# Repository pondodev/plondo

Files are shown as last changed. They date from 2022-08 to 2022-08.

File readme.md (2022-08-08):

# plondo

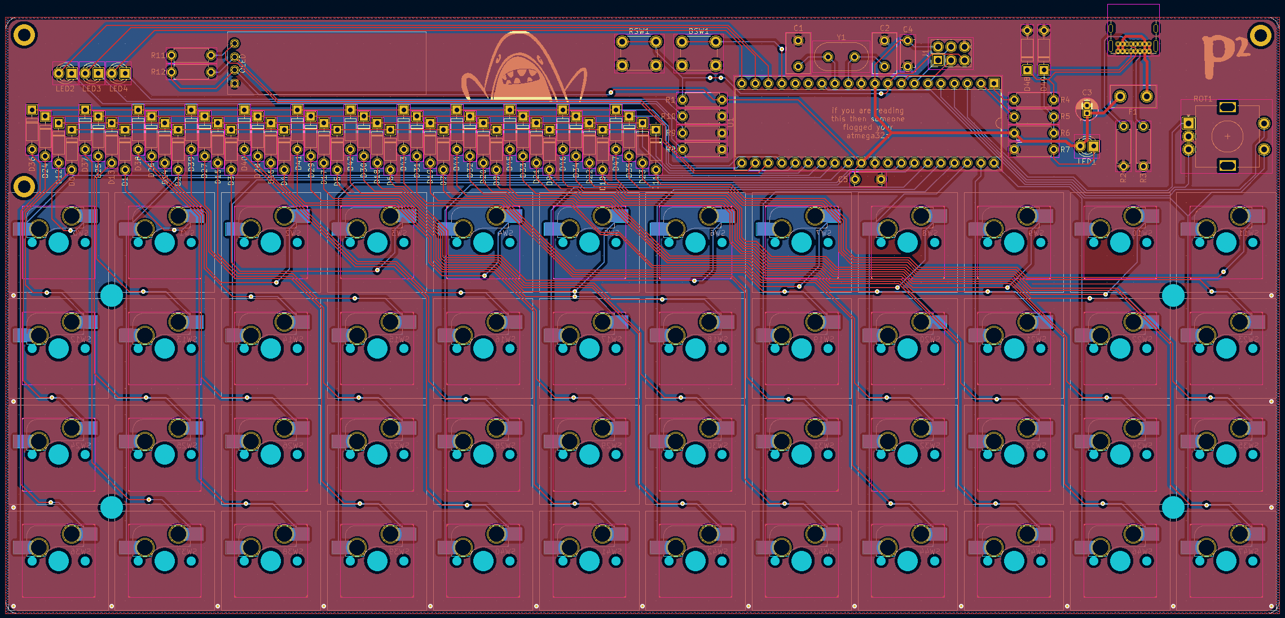
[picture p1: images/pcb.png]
plondo pcb


a plaid inspired 4x12 ortholinear keyboard with a rotary encoder and oled panel.

building plondo? then start at the [BOM](docs/1-bom.md)!

this is a work in progress by me, someone who is a software engineer and very much not qualified to do this kind of
thing. i'm going to do it anyway.

if you're missing symbols/footprints then make sure you run `git submodule init && git submodule update` to pull the
relevant libraries down.

this keyboard derives from the [plaid](https://github.com/hsgw/plaid) and the
[mysterium](https://github.com/coseyfannitutti/mysterium).

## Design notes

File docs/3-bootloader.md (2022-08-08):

# bootloader

to flash the bootloader onto your atmega32a, you need to have some sort of in system programmer (ISP) such as a usbasp
programmer or an arduino. if you don't have one, they're pretty cheap online.
[this is the one that i use](https://core-electronics.com.au/usbasp-usbisp-3-3v-5v-avr-programmer.html), but any ISP
capable of programming AVR chips will do.

next, clone [my fork of usbasploader](https://github.com/pondodev/USBaspLoader) locally and make sure to change the
`PROGRAMMER` variable in `Makefile.inc` to be the programmer that you're using. then simply connect your ISP to your
computer and to the ISP header (J1) on the PCB and run `make fuse && make flash`.

once you're done here, move onto [flashing and testing your PCB](4-flashing.md)

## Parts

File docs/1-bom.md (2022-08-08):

# bill of materials

before you get started, make sure you have the following parts to build your plondo. all parts are through hole unless
otherwise specified.

- 1x plondo PCB set
    - this includes the switch plate, base plate, and main pcb
- 1x atmega32a-p
- 1x 40 pin IC socket
- 48x 1N4148 diodes
- 2x 3.6V zener diodes
- 2x 100nF capacitors
- 1x 4.7uF capacitor
- 2x 20pF capacitors
- 1x USB-4085
- 1x 500mA 5mm pitch fuse
- 1x 16MHz crystal
- 2x push buttons
- 4x LEDs (1 power, 3 indicator)
- 3x 10k ohm resistors
- 4x 1.5k ohm resistors
- 2x 5.1k ohm resistors
- 2x 75 ohm resistors
- 1x ec11 rotary encoder
    - probably also get a knob to go on it
- 48x kailh mx hotswap terminals
- 48x mx compatible switches
- 1x ssd1306 128x32 oled screen
- 1x 2x3 2.54mm pin header
- 14x m2 screws
- 9x m2 spacers (TODO: figure out the sizes we need. 4 for the middle of the board, 5 for the top)
- 1x acrylic cover (optional)

you should probably also have the following tools

- soldering iron
- solder sucker and wick
    - just to clean up joints and desolder if you make mistakes. skip this if you're a giga-chad
- tweezers
- flux
    - this is for the usb c port. good luck without it
- ISP
    - i use a usbasp programmer, these things are super cheap online just make sure you have one for the bootloader
- small screwdriver
- multimeter
    - optional, but helpful for testing your soldering if you think it's dodgy

now that you have all the pieces you need, time to [start building](2-build-guide.md)

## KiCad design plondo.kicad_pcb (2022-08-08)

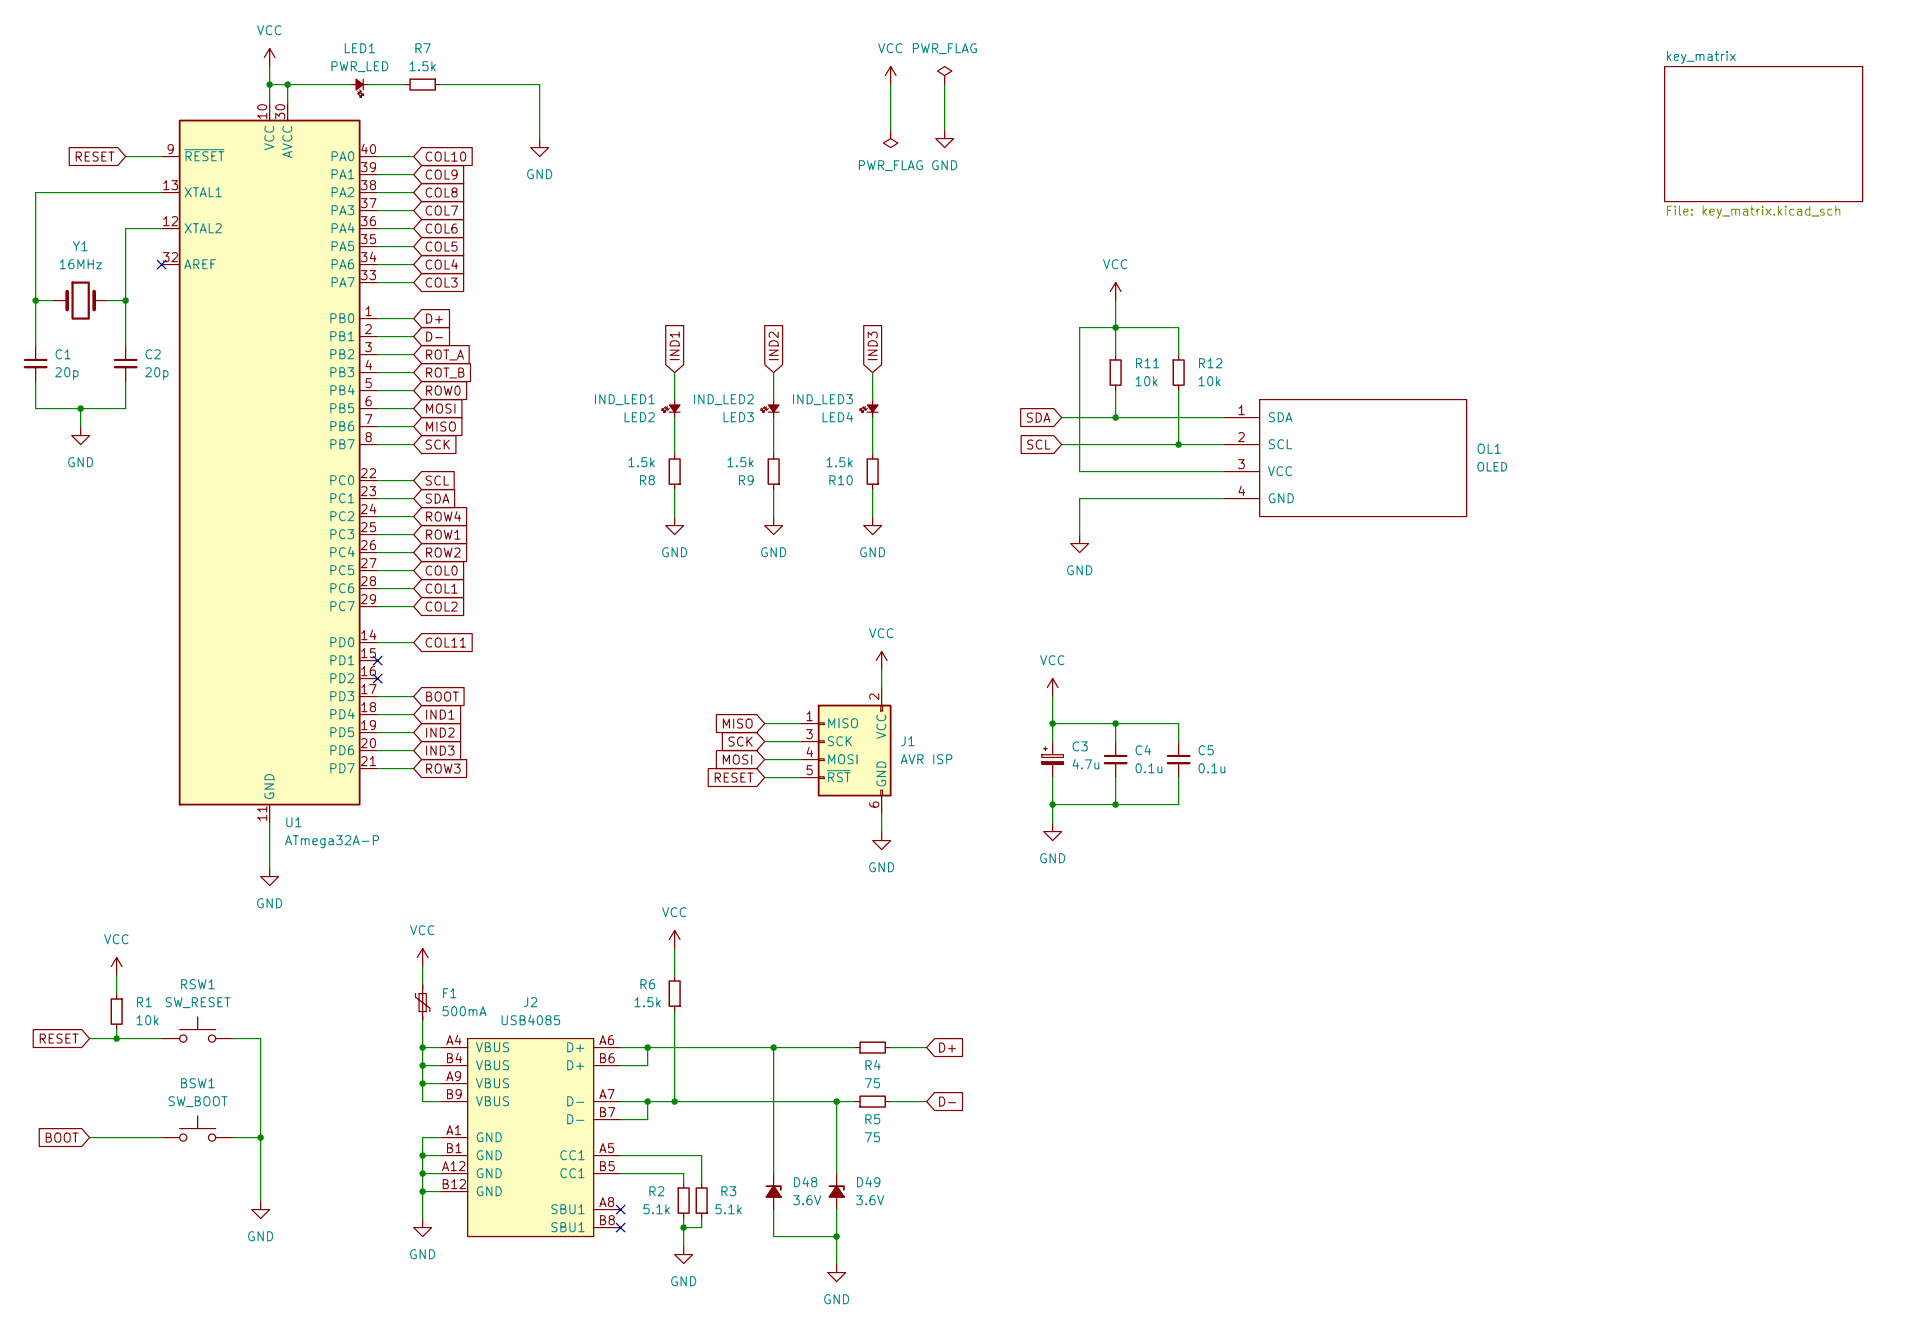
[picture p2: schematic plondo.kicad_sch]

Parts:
BSW1: SW_BOOT; SW_PUSH_6mm_H4.3mm
C1, C2: 20p; C_Disc_D7.5mm_W4.4mm_P5.00mm
C3: 4.7u; CP_Radial_D4.0mm_P1.50mm
C4, C5: 0.1u; C_Disc_D5.0mm_W2.5mm_P5.00mm
D48, D49: 3.6V; D_DO-35_SOD27_P7.62mm_Horizontal
F1: 500mA; Fuse_Littelfuse_395Series
J1: AVR ISP; PinHeader_2x03_P2.54mm_Vertical
J2: USB4085; Farnell 2924867
LED1: PWR_LED; LED_D3.0mm
LED2: IND_LED1; LED_D3.0mm
LED3: IND_LED2; LED_D3.0mm
LED4: IND_LED3; LED_D3.0mm
OL1: OLED; OLED_v2
R1, R11, R12: 10k; R_Axial_DIN0207_L6.3mm_D2.5mm_P7.62mm_Horizontal
R2, R3: 5.1k; R_Axial_DIN0207_L6.3mm_D2.5mm_P7.62mm_Horizontal
R4, R5: 75; R_Axial_DIN0207_L6.3mm_D2.5mm_P7.62mm_Horizontal
R6, R7, R8, R9, R10: 1.5k; R_Axial_DIN0207_L6.3mm_D2.5mm_P7.62mm_Horizontal
RSW1: SW_RESET; SW_PUSH_6mm_H4.3mm
U1: ATmega32A-P; DIP-40_W15.24mm_Socket
Y1: 16MHz; Resonator-2Pin_W10.0mm_H5.0mm

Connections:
BOOT: BSW1.1, U1.17 (PD3)
COL0: U1.27 (PC5); also elsewhere on the board
COL1: U1.28 (PC6); also elsewhere on the board
COL2: U1.29 (PC7); also elsewhere on the board
COL3: U1.33 (PA7); also elsewhere on the board
COL4: U1.34 (PA6); also elsewhere on the board
COL5: U1.35 (PA5); also elsewhere on the board
COL6: U1.36 (PA4); also elsewhere on the board
COL7: U1.37 (PA3); also elsewhere on the board
COL8: U1.38 (PA2); also elsewhere on the board
COL9: U1.39 (PA1); also elsewhere on the board
COL10: U1.40 (PA0); also elsewhere on the board
COL11: U1.14 (PD0); also elsewhere on the board
D+: R4.2, U1.1 (PB0)
D-: R5.2, U1.2 (PB1)
GND: BSW1.2, C1.2, C2.2, C3.2, C4.2, C5.2, D48.2 (A), D49.2 (A), J1.6 (GND), J2.A1 (GND), J2.A12 (GND), J2.B1 (GND), J2.B12 (GND), OL1.4 (GND), R2.2, R3.1, R7.1, R8.1, R9.1, R10.1, RSW1.2, U1.11 (GND), U1.31 (GND); also elsewhere on the board
IND1: LED2.2, U1.18 (PD4)
IND2: LED3.2, U1.19 (PD5)
IND3: LED4.2, U1.20 (PD6)
MISO: J1.1 (MISO), U1.7 (PB6)
MOSI: J1.4 (MOSI), U1.6 (PB5)
unnamed: C1.1, U1.13 (XTAL1), Y1.1
unnamed: C2.1, U1.12 (XTAL2), Y1.2
unnamed: D48.1 (K), J2.A6 (D+), J2.B6 (D+), R4.1
unnamed: D49.1 (K), J2.A7 (D-), J2.B7 (D-), R5.1, R6.1
unnamed: F1.1, J2.A4 (VBUS), J2.A9 (VBUS), J2.B4 (VBUS), J2.B9 (VBUS)
unnamed: J2.A5 (CC1), R3.2
unnamed: J2.B5 (CC1), R2.1
unnamed: LED1.1, R7.2
unnamed: LED2.1, R8.2
unnamed: LED3.1, R9.2
unnamed: LED4.1, R10.2
RESET: J1.5 (~RST), R1.2, RSW1.1, U1.9 (~RESET)
ROT_A: U1.3 (PB2); also elsewhere on the board
ROT_B: U1.4 (PB3); also elsewhere on the board
ROW0: U1.5 (PB4); also elsewhere on the board
ROW1: U1.25 (PC3); also elsewhere on the board
ROW2: U1.26 (PC4); also elsewhere on the board
ROW3: U1.21 (PD7); also elsewhere on the board
ROW4: U1.24 (PC2); also elsewhere on the board
SCK: J1.3 (SCK), U1.8 (PB7)
SCL: OL1.2 (SCL), R12.2, U1.22 (PC0)
SDA: OL1.1 (SDA), R11.2, U1.23 (PC1)
VCC: C3.1, C4.1, C5.1, F1.2, J1.2 (VCC), LED1.2, OL1.3 (VCC), R1.1, R6.2, R11.1, R12.1, U1.10 (VCC), U1.30 (AVCC)

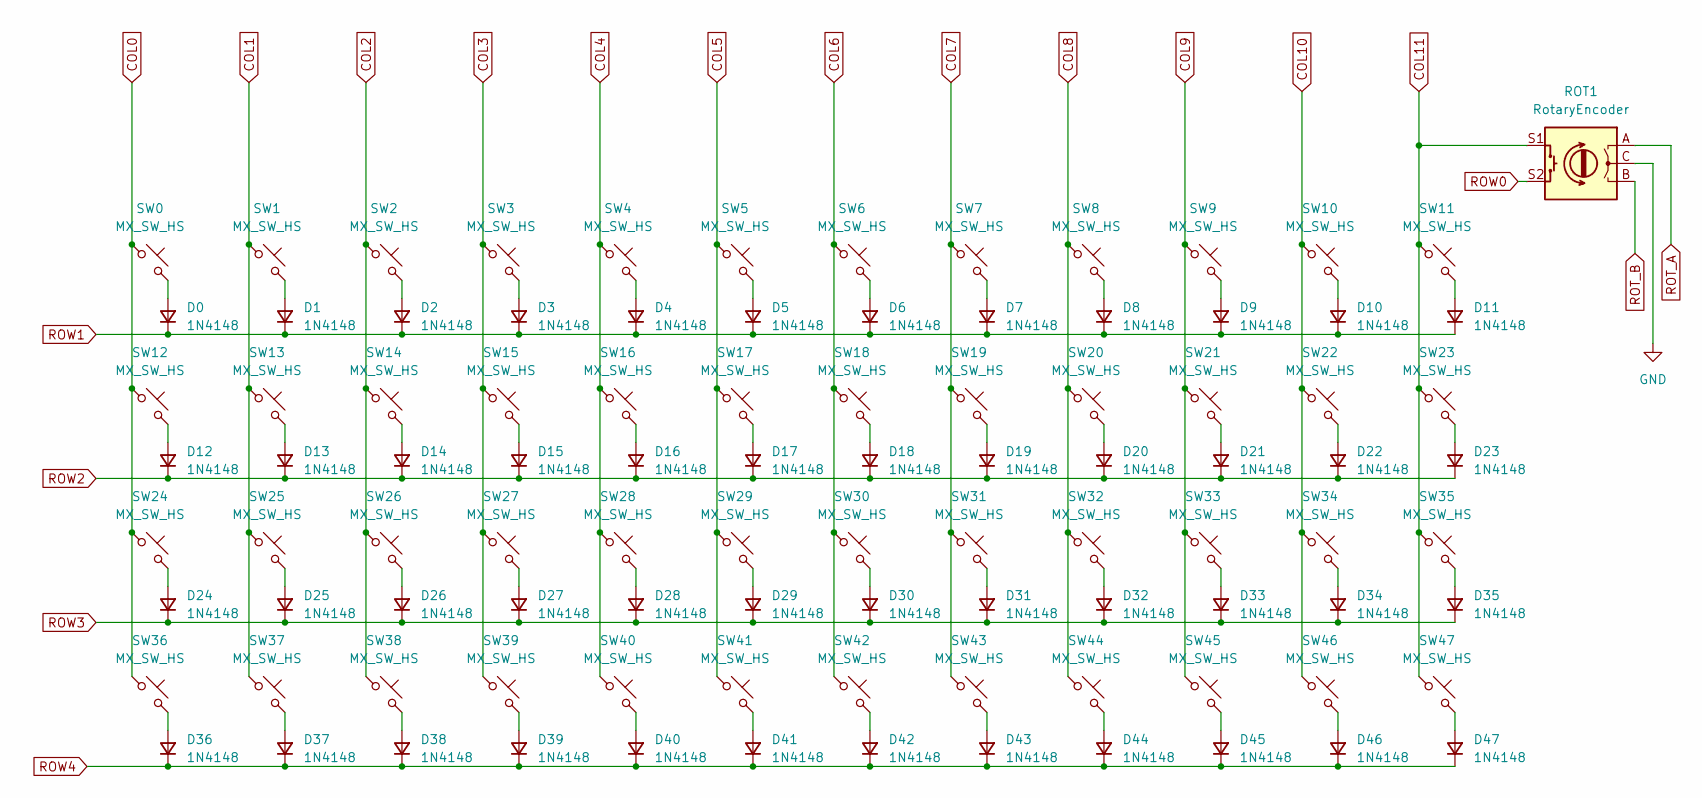
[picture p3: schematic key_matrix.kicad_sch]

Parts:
D0, D1, D2, D3, D4, D5, D6, D7, D8, D9, D10, D11, D12, D13, D14, D15, D16, D17, D18, D19, D20, D21, D22, D23, D24, D25, D26, D27, D28, D29, D30, D31, D32, D33, D34, D35, D36, D37, D38, D39, D40, D41, D42, D43, D44, D45, D46, D47: 1N4148; D_DO-35_SOD27_P7.62mm_Horizontal
ROT1: RotaryEncoder; RotaryEncoder_Alps_EC11E-Switch_Vertical_H20mm
SW0, SW1, SW2, SW3, SW4, SW5, SW6, SW7, SW8, SW9, SW10, SW11, SW12, SW13, SW14, SW15, SW16, SW17, SW18, SW19, SW20, SW21, SW22, SW23, SW24, SW25, SW26, SW27, SW28, SW29, SW30, SW31, SW32, SW33, SW34, SW35, SW36, SW37, SW38, SW39, SW40, SW41, SW42, SW43, SW44, SW45, SW46, SW47: MX_SW_HS; SW_MX_HS_1u

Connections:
COL0: SW0.1, SW12.1, SW24.1, SW36.1; also elsewhere on the board
COL1: SW1.1, SW13.1, SW25.1, SW37.1; also elsewhere on the board
COL2: SW2.1, SW14.1, SW26.1, SW38.1; also elsewhere on the board
COL3: SW3.1, SW15.1, SW27.1, SW39.1; also elsewhere on the board
COL4: SW4.1, SW16.1, SW28.1, SW40.1; also elsewhere on the board
COL5: SW5.1, SW17.1, SW29.1, SW41.1; also elsewhere on the board
COL6: SW6.1, SW18.1, SW30.1, SW42.1; also elsewhere on the board
COL7: SW7.1, SW19.1, SW31.1, SW43.1; also elsewhere on the board
COL8: SW8.1, SW20.1, SW32.1, SW44.1; also elsewhere on the board
COL9: SW9.1, SW21.1, SW33.1, SW45.1; also elsewhere on the board
COL10: SW10.1, SW22.1, SW34.1, SW46.1; also elsewhere on the board
COL11: ROT1.S1, SW11.1, SW23.1, SW35.1, SW47.1; also elsewhere on the board
GND: ROT1.C; also elsewhere on the board
unnamed: D0.2 (A), SW0.2
unnamed: D1.2 (A), SW1.2
unnamed: D2.2 (A), SW2.2
unnamed: D3.2 (A), SW3.2
unnamed: D4.2 (A), SW4.2
unnamed: D5.2 (A), SW5.2
unnamed: D6.2 (A), SW6.2
unnamed: D7.2 (A), SW7.2
unnamed: D8.2 (A), SW8.2
unnamed: D9.2 (A), SW9.2
unnamed: D10.2 (A), SW10.2
unnamed: D11.2 (A), SW11.2
unnamed: D12.2 (A), SW12.2
unnamed: D13.2 (A), SW13.2
unnamed: D14.2 (A), SW14.2
unnamed: D15.2 (A), SW15.2
unnamed: D16.2 (A), SW16.2
unnamed: D17.2 (A), SW17.2
unnamed: D18.2 (A), SW18.2
unnamed: D19.2 (A), SW19.2
unnamed: D20.2 (A), SW20.2
unnamed: D21.2 (A), SW21.2
unnamed: D22.2 (A), SW22.2
unnamed: D23.2 (A), SW23.2
unnamed: D24.2 (A), SW24.2
unnamed: D25.2 (A), SW25.2
unnamed: D26.2 (A), SW26.2
unnamed: D27.2 (A), SW27.2
unnamed: D28.2 (A), SW28.2
unnamed: D29.2 (A), SW29.2
unnamed: D30.2 (A), SW30.2
unnamed: D31.2 (A), SW31.2
unnamed: D32.2 (A), SW32.2
unnamed: D33.2 (A), SW33.2
unnamed: D34.2 (A), SW34.2
unnamed: D35.2 (A), SW35.2
unnamed: D36.2 (A), SW36.2
unnamed: D37.2 (A), SW37.2
unnamed: D38.2 (A), SW38.2
unnamed: D39.2 (A), SW39.2
unnamed: D40.2 (A), SW40.2
unnamed: D41.2 (A), SW41.2
unnamed: D42.2 (A), SW42.2
unnamed: D43.2 (A), SW43.2
unnamed: D44.2 (A), SW44.2
unnamed: D45.2 (A), SW45.2
unnamed: D46.2 (A), SW46.2
unnamed: D47.2 (A), SW47.2
ROT_A: ROT1.A; also elsewhere on the board
ROT_B: ROT1.B; also elsewhere on the board
ROW0: ROT1.S2; also elsewhere on the board
ROW1: D0.1 (K), D1.1 (K), D2.1 (K), D3.1 (K), D4.1 (K), D5.1 (K), D6.1 (K), D7.1 (K), D8.1 (K), D9.1 (K), D10.1 (K), D11.1 (K); also elsewhere on the board
ROW2: D12.1 (K), D13.1 (K), D14.1 (K), D15.1 (K), D16.1 (K), D17.1 (K), D18.1 (K), D19.1 (K), D20.1 (K), D21.1 (K), D22.1 (K), D23.1 (K); also elsewhere on the board
ROW3: D24.1 (K), D25.1 (K), D26.1 (K), D27.1 (K), D28.1 (K), D29.1 (K), D30.1 (K), D31.1 (K), D32.1 (K), D33.1 (K), D34.1 (K), D35.1 (K); also elsewhere on the board
ROW4: D36.1 (K), D37.1 (K), D38.1 (K), D39.1 (K), D40.1 (K), D41.1 (K), D42.1 (K), D43.1 (K), D44.1 (K), D45.1 (K), D46.1 (K), D47.1 (K); also elsewhere on the board

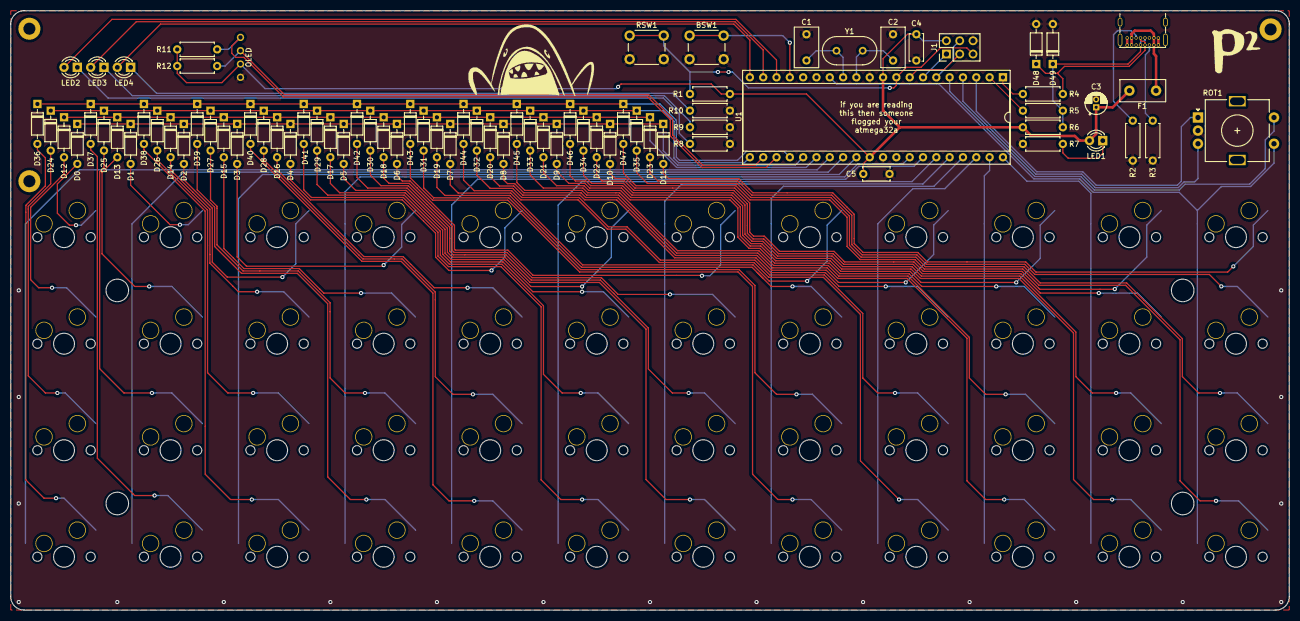
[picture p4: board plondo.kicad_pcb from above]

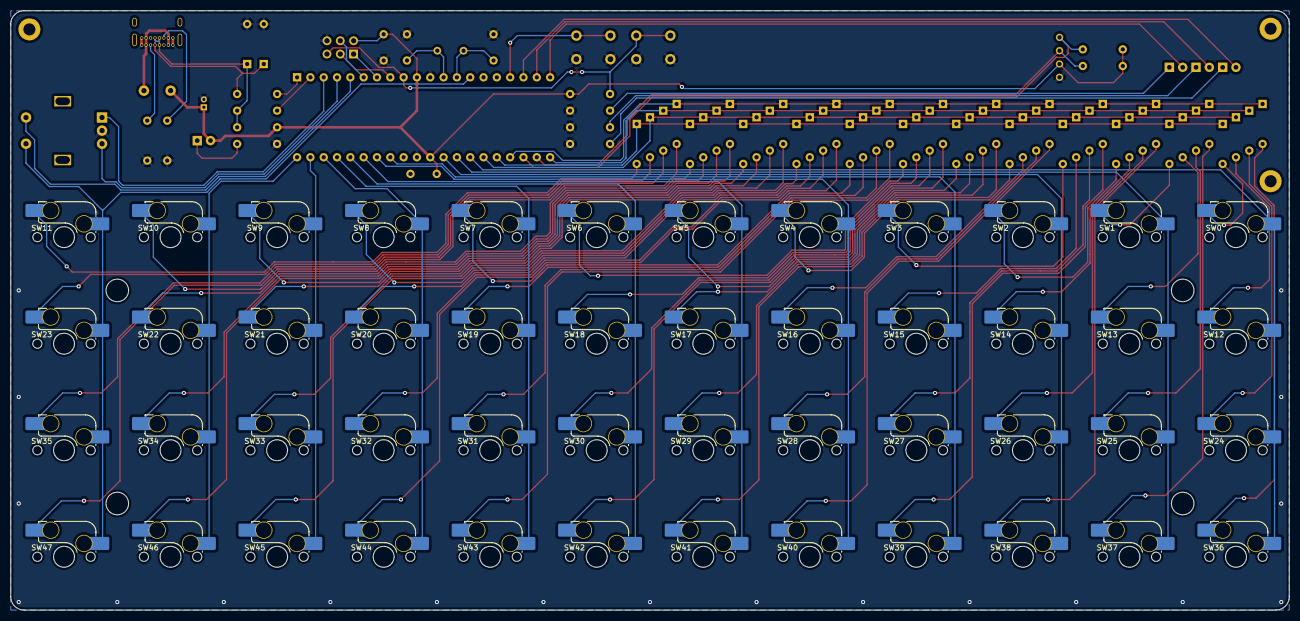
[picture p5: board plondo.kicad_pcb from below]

Board: 2 copper layers, 243.8 x 114.3 mm, 132 parts (48 on the bottom side), 92 nets.

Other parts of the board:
Ref**: Val**; spacer_m2
Ref**#2, Ref**#3, Ref**#4: Val**; spacer_m2

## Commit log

2022-07-29 add libs as submodules, fix up usb c wiring
    [plondo.kicad_sch]
2022-07-30 complete main circuitry
    [key_matrix.kicad_sch, plondo.kicad_sch]
2022-07-31 add indicator LEDs
    [key_matrix.kicad_sch, plondo.kicad_sch]
2022-07-31 add missing connections + oled
    [key_matrix.kicad_sch, plondo.kicad_sch]
2022-07-31 first pass of pcb layout, fix footprints
    [plondo.kicad_pcb, plondo.kicad_sch]
2022-07-31 add pullups for i2c lines
    [plondo.kicad_pcb, plondo.kicad_sch]
2022-07-31 edited schematics for clarity, position more of pcb
    [key_matrix.kicad_sch, plondo.kicad_pcb, plondo.kicad_sch]
2022-07-31 position all components on the pcb
    [plondo.kicad_pcb]
2022-08-02 rearrange pins + misc pcb arrangement fixes
    [key_matrix.kicad_sch, plondo.kicad_pcb, plondo.kicad_sch]
2022-08-02 bunch of routing done
    [plondo.kicad_pcb]
2022-08-03 finish connecting rows to diodes
    [plondo.kicad_pcb]
2022-08-03 start redoing my awful routing
    [plondo.kicad_pcb]
2022-08-04 complete connecting key matrix
    [plondo.kicad_pcb, plondo.kicad_sch]
2022-08-04 a lot more connections
    [plondo.kicad_pcb]
2022-08-05 connected all components on the pcb
    [plondo.kicad_pcb]
2022-08-07 rounded corners!
    [plondo.kicad_pcb]
2022-08-07 add nice silkscreen stuff, update readme
    [plondo.kicad_pcb]
2022-08-07 add ground planes, make vcc lines thicker
    [plondo.kicad_pcb]
2022-08-08 rearrange silkscreen references
    [plondo.kicad_pcb]
2022-08-08 add mounting holes, vias for ground planes
    [plondo.kicad_pcb]
2022-08-08 add bom
2022-08-08 add barebones baseplate
    [baseplate.kicad_pcb]
2022-08-09 add switchplate
    [switchplate.kicad_pcb]
